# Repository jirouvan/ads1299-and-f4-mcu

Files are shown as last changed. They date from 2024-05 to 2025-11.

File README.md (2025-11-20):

# ads1299-and-f4-mcu
这是一个基于STM32F407的无线脑电信号采集系统设计

### ads1299+stm32f407第七版.eprj 为一个嘉立创的项目文件，里面包含了原理图和pcb
(第七版对项目做了精简化处理，去掉了wifi模块和sd模块，同时也保留了这些模块的接口，可以通过外接的方式添加这些外设；做了数字电路和模拟电路的隔离，通过各自单点接入再分别铺铜最后窄接的方式实现)

(第六版整理了部分杂乱的线路，更新了经过测试后切实可行的3d外壳文件和面板文件，修改了部分引脚错位的现象)

(第五版相较于第四版，增加了3d外壳文件，修改了部分错位丝印，~~如今的项目已经是完全之龙~~(<-当我上句话在放屁))

(第四版相较于第三版更改了基础库器件，使用嘉立创smt贴片可以减少300元物料费，第三版和第四版在branches中)

### BOM_Board1_PCB_2024-03-31.xlsx 为BOM文件，里面包含了物料清单，可在立创商城索引且库存充足

### Gerber_PCB_2024-03-31.zip 为GerBer制板文件

### PickAndPlace_PCB_2024-03-31.xlsx 为坐标文件

### SCH_无线脑电信号采集系统V1.0_2024-03-31.pdf 为项目的原理图

### 3DShell_PCB.zip 为项目的3d外壳文件

### Panel_Panel_1_2024-04-28.epanm 为项目的面板文件
(DXF_PCB_2024-04-23.dxf 为制作面板的中间文件)

### SMT2404011843_T.png 和SMT2404241038_B.png 为项目的smt贴片文件，本项目只有顶(T)层贴片

#### 本项目尚在测试中，目前为V1.0版本，更稳定的版本请等待V2.0版本的更新

#### 欢迎各界人士批评指正，能谤讥于市朝闻寡人之耳者，受下赏；上书谏寡人者受中赏；能面刺寡人之过者，受上赏

#### 特别感谢广西嵌入式技术与智能系统重点实验室的大力支持，如果不是他们工作效率低下一直不批报销，我早就做完了

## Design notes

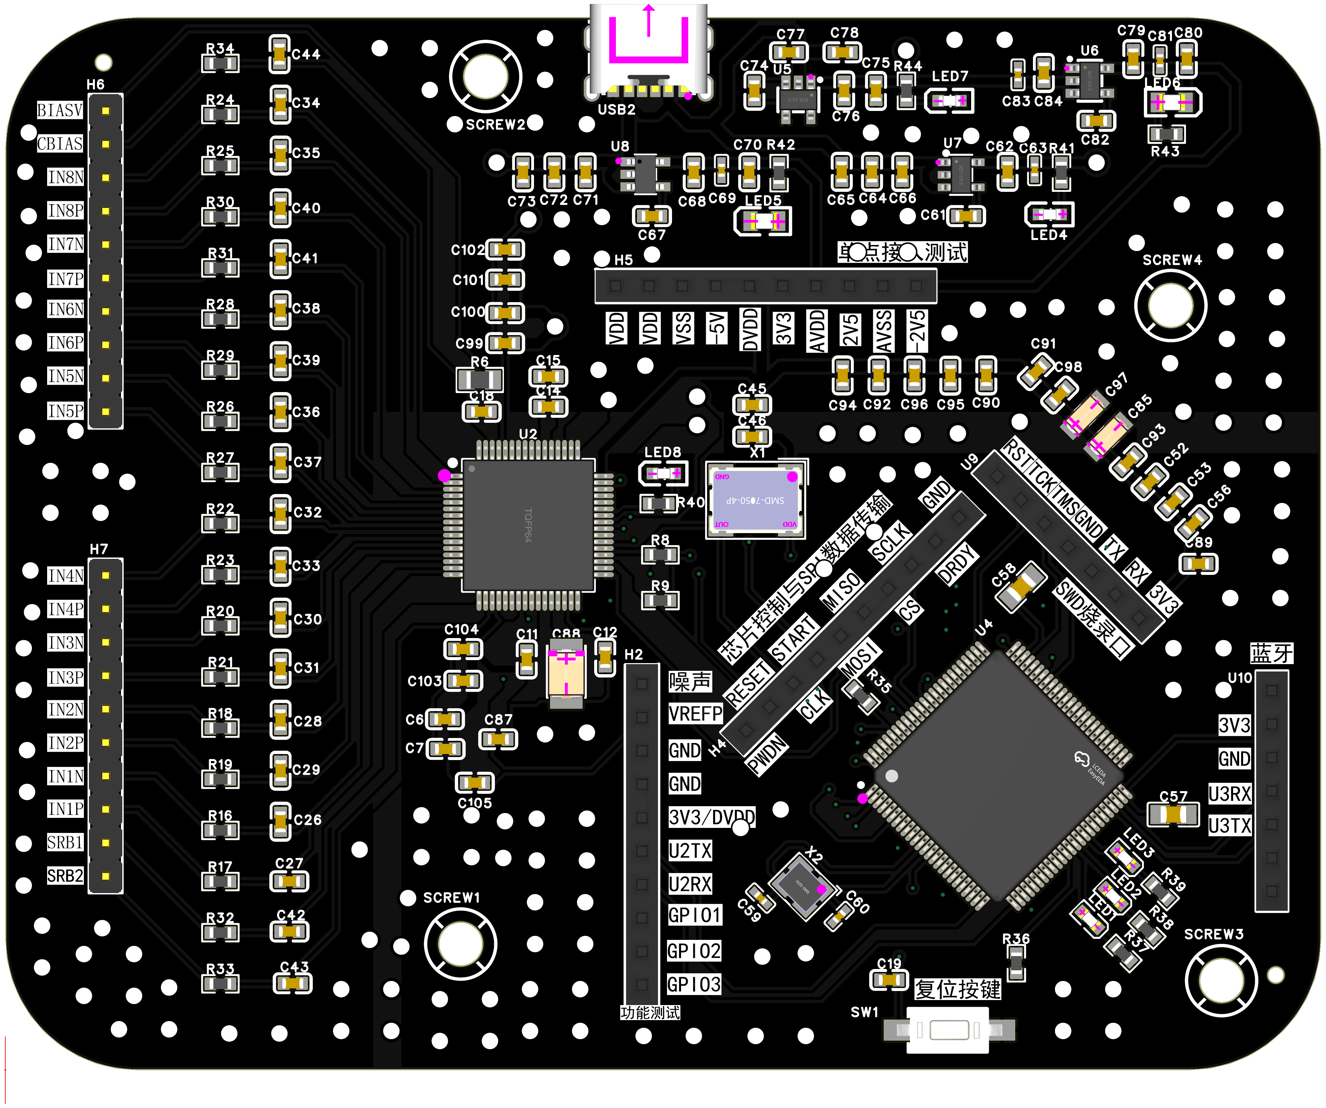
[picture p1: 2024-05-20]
SMT2405120395_T.png

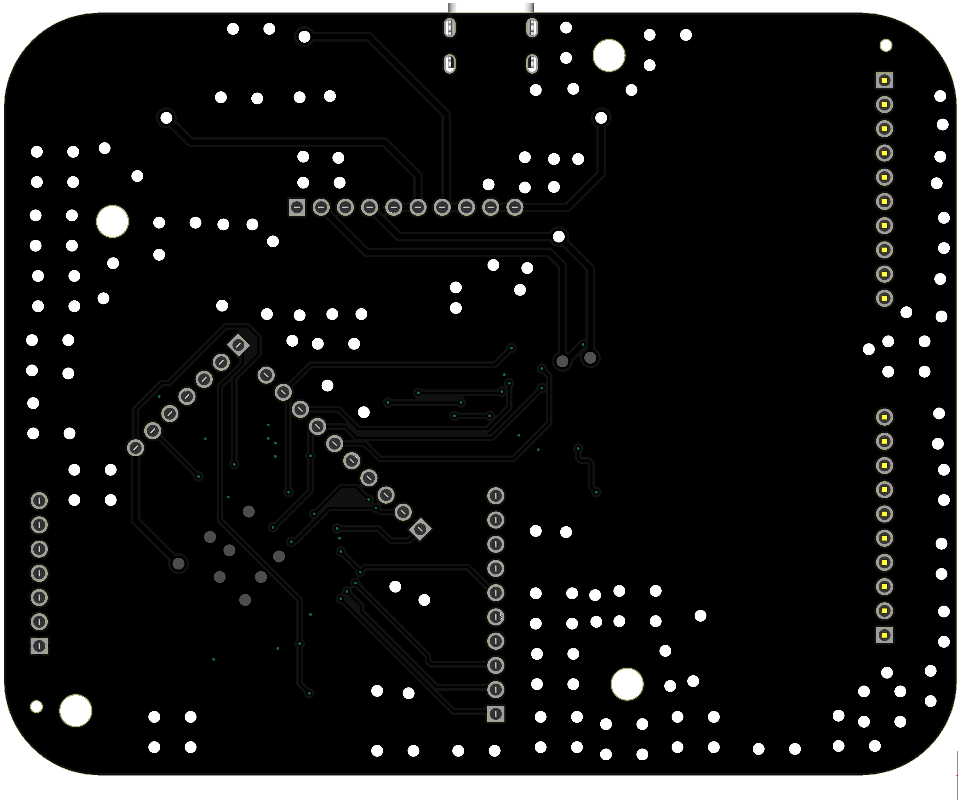
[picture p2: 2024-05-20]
SMT2405120395_B.png

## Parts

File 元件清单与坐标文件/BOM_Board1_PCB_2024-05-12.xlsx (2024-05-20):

No. | Quantity | Comment | Designator | Footprint | Value | Manufacturer Part | Manufacturer | Supplier Part | Supplier | LCSC Stock | LCSC Price
1 | 18 | 1uF | C6,C7,C11,C12,C15,C45,C61,C66,C67,C68,C73,C74,C75,C77,C80,C95,C99,C100 | C0603 | 1uF | CL10A105KB8NNNC | SAMSUNG(三星) | C15849 | LCSC | 29232 | 0.028523
2 | 18 | 100nF | C14,C19,C46,C52,C53,C56,C90,C91,C92,C93,C94,C96,C98,C101,C102,C103,C104,C105 | C0603 | 100nF | CC0603KRX7R9BB104 | YAGEO(国巨) | C14663 | LCSC | 338214 | 0.013981
3 | 1 | 1.5nF | C18 | C0603 | 1.5nF | 0603B152K500NT | FH(风华) | C1595 | LCSC | 43499 | 0.01328
4 | 19 | 4.7nF | C26,C27,C28,C29,C30,C31,C32,C33,C34,C35,C36,C37,C38,C39,C40,C41,C42,C43,C44 | C0603 | 4.7nF | 0603B472K500NT | FH(风华) | C53987 | LCSC | 7910 | 0.016267
5 | 2 | 2.2uF | C57,C58 | C0805 | 2.2uF | CL21A225KBQNNNE | SAMSUNG(三星) | C377773 | LCSC | 19110 | 0.116789
6 | 2 | 9pF | C59,C60 | C0402 | 9pF | TCC0402COG9R0D500AT | CCTC(三环) | C696893 | LCSC | 544 | 0.008363
7 | 11 | 10uF | C62,C64,C65,C70,C71,C72,C76,C78,C79,C84,C87 | C0603 | 10uF | CL10A106KP8NNNC | SAMSUNG(三星) | C19702 | LCSC | 15762 | 0.036642
8 | 4 | 2.2uF | C63,C69,C81,C83 | C0402 | 2.2uF | CL05A225MQ5NSNC | SAMSUNG(三星) | C12530 | LCSC | 13859 | 0.014687
9 | 1 | 10nF | C82 | C0603 | 10nF | 0603B103K500NT | FH(风华) | C57112 | LCSC | 36115 | 0.015082
10 | 2 | 1uF | C85,C97 | CASE-A_3216 | 1uF | TAJA105K016RNJ | Kyocera AVX | C7174 | LCSC | 15829 | 0.614167
11 | 1 | 100uF | C88 | CASE-B_3528 | 100uF | TAJB107K006RNJ | Kyocera AVX | C16133 | LCSC | 31917 | 0.9403
12 | 1 | 4.7uF | C89 | C0603 | 4.7uF | CL10A475KO8NNNC | SAMSUNG(三星) | C19666 | LCSC | 32682 | 0.06024
13 | 3 | PM254-1-10-Z-8.5 | H2,H4,H5 | HDR-TH_10P-P2.54-V-F |  | PM254-1-10-Z-8.5 | HCTL(华灿天禄) | C2897373 | LCSC | 1906 | 1.0043
14 | 2 | 2.54-1*10P针 | H6,H7 | HDR-TH_10P-P2.54-V-M-1 |  | 2.54-1*10P针 | BOOMELE(博穆精密) | C57369 | LCSC | 3052 | 0.2868
15 | 3 | KT-0603R | LED1,LED2,LED3 | LED0603-RD |  | KT-0603R | KENTO | C2286 | LCSC | 9759 | 0.03486
16 | 3 | KT-0603W | LED4,LED7,LED8 | LED0603-R-RD_WHITE |  | KT-0603W | KENTO | C2290 | LCSC | 4109 | 0.066771
17 | 2 | KT-0805G | LED5,LED6 | LED0805-R-RD |  | KT-0805G | KENTO | C2297 | LCSC | 4480 | 0.086736
18 | 1 | 1MΩ | R6 | R0805 | 1MΩ | 0805W8F1004T5E | UNI-ROYAL(厚声) | C17514 | LCSC | 7258 | 0.01123
19 | 8 | 10kΩ | R8,R9,R35,R36,R41,R42,R43,R44 | R0603 | 10kΩ | 0603WAF1002T5E | UNI-ROYAL(厚声) | C25804 | LCSC | 104796 | 0.005732
20 | 19 | 11kΩ | R16,R17,R18,R19,R20,R21,R22,R23,R24,R25,R26,R27,R28,R29,R30,R31,R32,R33,R34 | R0603 | 11kΩ | 0603WAF1102T5E | UNI-ROYAL(厚声) | C25950 | LCSC | 2970 | 0.006512
21 | 3 | 100Ω | R37,R38,R39 | R0603 | 100Ω | 0603WAF1000T5E | UNI-ROYAL(厚声) | C22775 | LCSC | 43180 | 0.006376
22 | 1 | 270Ω | R40 | R0603 | 270Ω | 0603WAF2700T5E | UNI-ROYAL(厚声) | C22966 | LCSC | 6888 | 0.006304
23 | 4 | M3螺丝 | SCREW1,SCREW2,SCREW3,SCREW4 | M3螺丝
24 | 1 | TS-1101-C-W | SW1 | SW-SMD_L6.0-W3.3-LS8.0 |  | TS-1101-C-W | XKB Connectivity(中国星坤) | C318938 | LCSC | 24083 | 0.231705
25 | 1 | ADS1299IPAGR | U2 | TQFP-64_L10.0-W10.0-P0.50-LS12.0-TL |  | ADS1299IPAGR | TI(德州仪器) | C476817 | LCSC | 341 | 297
26 | 1 | STM32F407VGT6 | U4 | LQFP-100_L14.0-W14.0-P0.50-LS16.0-BL |  | STM32F407VGT6 | ST(意法半导体) | C12345 | LCSC | 1405 | 26.4
27 | 1 | TPS60403DBVR | U5 | SOT-23-5_L3.0-W1.7-P0.95-LS2.8-BR |  | TPS60403DBVR | TI(德州仪器) | C11338 | LCSC | 6347 | 3.31
28 | 1 | TPS72325DBVR | U6 | SOT-23-5_L3.0-W1.7-P0.95-LS2.8-BR |  | TPS72325DBVR | TI(德州仪器) | C69932 | LCSC | 487 | 10.26
29 | 1 | TPS73233DBVR | U7 | SOT-23-5_L3.0-W1.7-P0.95-LS2.8-BL |  | TPS73233DBVR | TI(德州仪器) | C181459 | LCSC | 246 | 10.6
30 | 1 | TPS73225DBVR | U8 | SOT-23-5_L2.9-W1.6-P0.95-LS2.8-TL |  | TPS73225DBVR | TI(德州仪器) | C2758473 | LCSC | 125 | 9.06
31 | 2 | PM254-1-07-Z-8.5 | U9,U10 | HDR-TH_7P-P2.54-V-F |  | PM254-1-07-Z-8.5 | HCTL(华灿天禄) | C2897370 | LCSC | 2594 | 0.787103
32 | 1 | TYPE-C 6P(073) | USB2 | TYPE-C-SMD_TYPE-C-6P |  | TYPE-C 6P(073) | SHOU HAN(首韩) | C668623 | LCSC | 16524 | 0.254611
33 | 1 | 2.048MHz | X1 | OSC-SMD_4P-L7.0-W5.0-BL | 2.048MHz | S7D2.048000B20F30T | SCTF(星通时频) | C386898 | LCSC | 302 | 3.21
34 | 1 | 16MHz | X2 | OSC-SMD_4P-L3.2-W2.5-BL | 16MHz | X322516MLB4SI | YXC(扬兴晶振) | C13738 | LCSC | 13781 | 0.427144

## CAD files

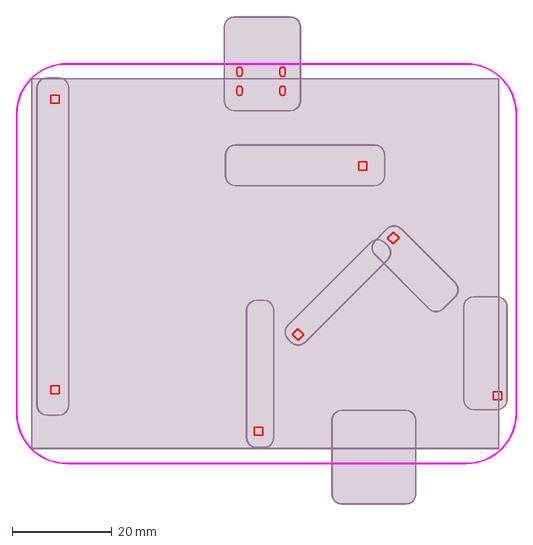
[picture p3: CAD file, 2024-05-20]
3d外壳与面板/DXF_PCB_2024-05-16.dxf
100.3 x 97.8 mm

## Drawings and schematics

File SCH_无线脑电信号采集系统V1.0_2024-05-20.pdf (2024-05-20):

# type-c接口电源

# HC-04蓝牙模块

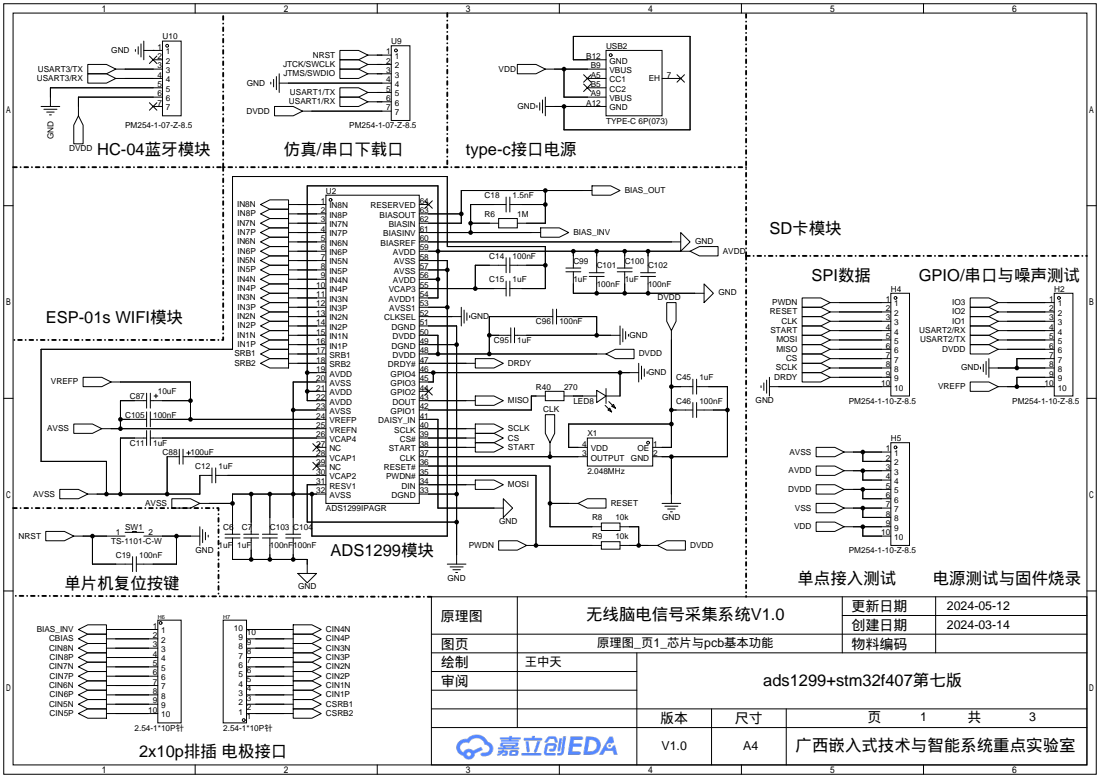
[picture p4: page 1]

VDD 50 PB12 51 PB13 52 PB14 53 PB15 54 PD8 55 PD9 56 PD10 57 PD11 58 PD12 59 PD13 60 PD14 61 PD15 62 PC6 63 PC7 64 PC8 65 PC9 66 PA8 67 PA9 68 PA10 69 PA11 70 PA12 71 PA13 72 VCAP_2 73 VSS 74 VDD 75 PA14 76 PA15 77 PC10 78 PC11 79 PC12 80 PD0 81 PD1 82 PD2 83 PD3 84 PD4 85 PD5 86 PD6 87 PD7 88 PB3 89 PB4 90 PB5 91 PB6 92 PB7 93 BOOT0 94 PB8 95 PB9 96 PE0 97 PE1 98 VSS 99 VDD 100

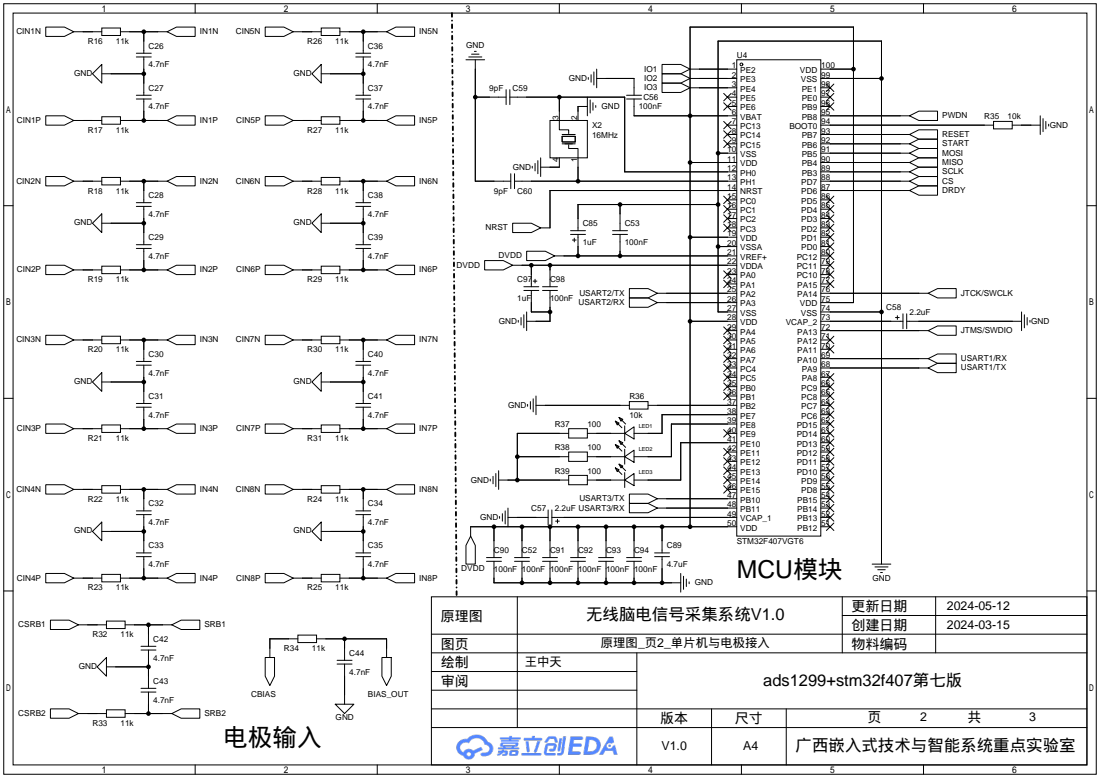
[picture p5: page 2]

# ldo模块/+5转+2.5

# VDD 是 +5V

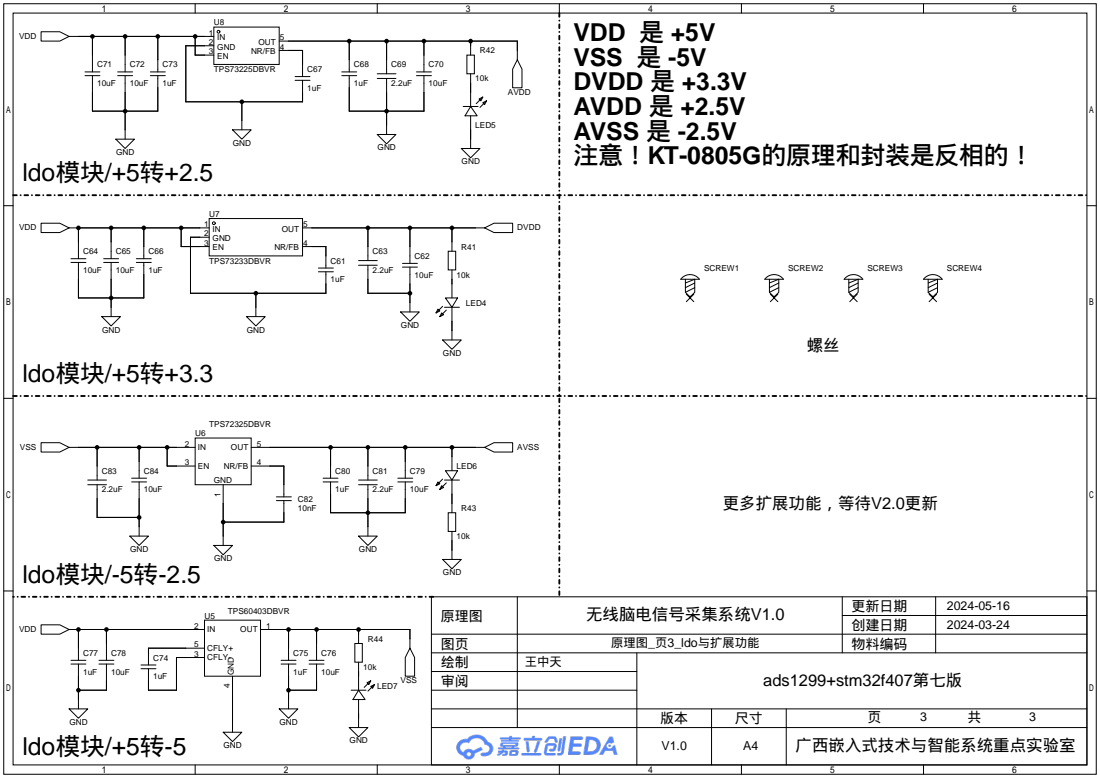
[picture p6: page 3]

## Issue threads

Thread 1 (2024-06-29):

求教

weiym07, 2024-06-29:
求教

weiym07, 2024-06-29:
您的实现代码我可以学习一下吗？

weiym07, 2024-06-29:
您的ADS1299的EPRO文件 能在上传一下吗  球球了

dxqqq, 2024-07-03:
兄弟你好 ，可以再上传一次吗，想参考一下 感谢！

weiym07, 2024-07-03:
兄弟你也在做脑电吗？

dxqqq, 2024-07-04:
是的

TingYhan, 2024-07-07:
兄弟们有没有参考代码，十分感谢！！！

zhihaoxi, 2024-12-03:
大佬，借个代码看看呗，球球了：）

weiym07, 2024-12-03:
现在 嘉立创有开源ads1299项目 非常完整&nbsp; 你可以去看一下

---原始邮件---
发件人: ***@***.***&gt;
发送时间: 2024年12月3日(周二) 中午11:07
收件人: ***@***.***&gt;;
抄送: ***@***.******@***.***&gt;;
主题: Re: [jirouvan/ads1299-and-f4-mcu] 求教 (Issue #1)

大佬，借个代码看看呗，球球了：）

—
Reply to this email directly, view it on GitHub, or unsubscribe.
You are receiving this because you authored the thread.Message ID: ***@***.***&gt;

jirouvan, 2024-12-22:
我的上位机写的全是bug，暂时只开源硬件部分，你可以先用YuTao的，他写的快

jirouvan, 2024-12-22:
spi通信直接用的正点原子官方库，我写的比较乱，整理一下上传

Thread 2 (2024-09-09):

老哥 求教

weiym07, 2024-09-09:
ads1299的SPI通信实现的代码能分享一下吗？有偿QQ1163389496

jirouvan, 2024-12-22:
之前做别的工作去了，我的代码比较乱，整理一下上传，开源不需要有偿

weiym07, 2024-12-22:
我已经跑出来了&nbsp; &nbsp;最多能测出来眼电，脑电信号被噪声淹没了， 上位机我用的labview写的凑合能用，&nbsp; 老哥，ads1299pcb的模拟前端如何布线，才能减小噪声.

---原始邮件---
发件人: "zt ***@***.***&gt;
发送时间: 2024年12月22日(周日) 晚上9:04
收件人: ***@***.***&gt;;
抄送: ***@***.******@***.***&gt;;
主题: Re: [jirouvan/ads1299-and-f4-mcu] 老哥 求教 (Issue #2)

之前做别的工作去了，我的代码比较乱，整理一下上传，开源不需要有偿

—
Reply to this email directly, view it on GitHub, or unsubscribe.
You are receiving this because you authored the thread.Message ID: ***@***.***&gt;

PY-UP, 2024-12-24:
最近在学习相关的内容，代码可以分享一下吗？QQ:487870774

xiaoliangsjd, 2025-02-26:
老哥，您的项目特别有用，请问代码可以提供下吗，我正在学习ads1299，特别需要，谢谢啦，qq：2030601562

msx12123, 2025-05-17:
老哥，想要求一份代码，这个项目跟我的课题很像，还想问一下这项目是采集人脑电还是老鼠脑电啊，谢谢啦，QQ:1195093495
